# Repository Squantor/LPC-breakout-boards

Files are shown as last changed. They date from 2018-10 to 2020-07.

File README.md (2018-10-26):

# LPC microcontroller breakout boards
This is a small collection breakout boards for various LPC microcontrollers, in the future I might add others to the mix. Currently there are a set of eagle and kicad designs, the eagle designs are legacy and might get replaced in the future as currently I am fully comitting on using kicad.
## checkout notes
This repository contains a few submodules, so after checking out do not forget to also check out the submodules.
```
git clone https://github.com/Squantor/LPC-breakout-boards.git
git submodule init
git submodule update
```
Submodules are my private kicad library that are used in my projects. I do try to use the kicad components as much as possible but for certain component types they are less then optimal.

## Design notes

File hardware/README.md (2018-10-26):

# KiCad LPC breakout boards
We have here a bunch of LPC series microcontroller breakouts. Each of the kicad project dirs contains its own README.
All of the breakouts are using the [squantorPcbLibrary](https://github.com/Squantor/squantorPcbLibrary.git) where needed. Gerbers, and other plots are located per project but only when they have been sent off to production.

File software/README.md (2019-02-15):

# LPC breakout software
Here are some programs to help testing newly built breakout boards, the following tests are executed:
* Programming of the microcontroller
* GPIO's tested for shorts to VDD/VSS and excessive leakage
* Crystal oscillator

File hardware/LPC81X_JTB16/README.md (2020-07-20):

# LPC812 XSON16 breakout
Breakout board for the LPC812 in XSON16 package. This is more or less a test bed to do everything as small as possible. So 0201 components, tiny crystal, everything tiny!
## TODO's
Still some things need to be done:
* schematic entry 
* PCB layout
* Review with one night in between
* Produce at [OSHPARK](https://oshpark.com/)
* Assemble
* Test & characterise
* update Readme.md with pictures and BOM
## BOM
* LPC812M101JTB16
* All passives are 0201

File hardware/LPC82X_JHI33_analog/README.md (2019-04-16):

# LPC824 QFN33 breakout 4 layer version, Analog evaluator
This is a LPC824 breakout for the QFN33 package, all GPIO's are brought out and contains SWD programming header, crystal footprint and a decoupling network (capacitors and ferrite beads) for the analog supplies.

This breakout can be used in prototyping PCB as the breakout headers match the 2.54mm pitch of such a PCB.

This board has a 4 layer stackup to provide a low impedance power supply. The power is also distributed into a digital and analog plane to measure differences in performance of the ADC.
## TODO's
Still some things need to be done:
* layout (Done)
* Review after a day (Done)
* Produce [OSHpark](https://oshpark.com/shared_projects/RuvO87MR) (Done)
* Assemble (Done)
* Full test program (Done)
* Upload some pictures and expand description (Done)
## BOM
Due to the general shortage of passive components, where mentioned, just whatever you can find.
* 0402 100nF 6.3V (generic)
* 0402 Ferrite bead (Murata BLM15PX601SN1D 600Ohm 900mA [Farnell](https://uk.farnell.com/2840091)
* 0402 100Ohm resistors for series dampening of programming lines
* 0402 100KOhm resistors for pullup on Reset, SWDIO and pulldown on SWDCLK
* 0603 1uF 6.3V (generic)
* LPC824 microcontroller [Farnell](https://uk.farnell.com/2890181)
* 12MHz crystal (optional) [Farnell](https://uk.farnell.com/2853917)
* The header I usually get from this vendor on [Ebay](https://www.ebay.com/usr/yixue2010), bit slow shipping and not the cheapest but the parts are good, he has a pretty sizable selection of connectors. 
## Pictures
See the non analog one, physically not a lot of differences.

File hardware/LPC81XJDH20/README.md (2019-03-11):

# LPC81X SSOP20 breakout board
Breakout board of [LPC81X](https://www.nxp.com/products/processors-and-microcontrollers/arm-based-processors-and-mcus/lpc-cortex-m-mcus/lpc800-series-cortex-m0-plus-mcus/low-cost-microcontroll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) microcontroller.
## TODO's
Still some things need to be done:
* Produce at [OSHPARK](https://oshpark.com/shared_projects/42cLyk7C)
* Assemble (TODO)
* Update test program (TODO)
* Update Readme.md with pictures and BOM (TODO)
* Put on sale on tindie

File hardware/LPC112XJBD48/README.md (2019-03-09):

# LPC112X QFP48 breakout board
Breakout board of [LPC112X](https://www.nxp.com/products/processors-and-microcontrollers/arm-based-processors-and-mcus/lpc-cortex-m-mcus/lpc1100-cortex-m0-plus-m0/scalable-entry-level-32-bit-mi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)
## TODO's
Still some things need to be done:
* schematic entry (TODO)
* PCB layout (TODO)
* Review with one night in between (TODO)
* Produce at [OSHPARK](https://oshpark.com/) (TODO)
* Assemble (TODO)
* Test & characterise (TODO)
* update Readme.md with pictures and BOM (TODO)

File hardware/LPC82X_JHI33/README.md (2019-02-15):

# LPC824 QFN33 breakout 2 layer version
This is a LPC824 breakout for the QFN33 package, all GPIO's are brought out and contains SWD programming header, crystal footprint and a decoupling network (capacitors and ferrite beads) for the analog supplies.

This breakout can be used in prototyping PCB as the breakout headers match the 2.54mm pitch of such a PCB.
## TODO's
Still some things need to be done:
* layout (Done)
* Review after a day (Done)
* Produce [OSHpark](https://oshpark.com/shared_projects/RuvO87MR) (Done)
* Assemble (Done)
* Full test program (Done)
* Upload some pictures and expand description (Done)
## BOM
Due to the general shortage of passive components, where mentioned, just whatever you can find.
* 0402 100nF 6.3V (generic)
* 0402 Ferrite bead (Murata BLM15PX601SN1D 600Ohm 900mA [Farnell](https://uk.farnell.com/2840091)
* 0402 100Ohm resistors for series dampening of programming lines
* 0402 100KOhm resistors for pullup on Reset, SWDIO and pulldown on SWDCLK
* 0603 1uF 6.3V (generic)
* LPC824 microcontroller [Farnell](https://uk.farnell.com/2890181)
* 12MHz crystal (optional) [Farnell](https://uk.farnell.com/2853917)
* The header I usually get from this vendor on [Ebay](https://www.ebay.com/usr/yixue2010), bit slow shipping and not the cheapest but the parts are good, he has a pretty sizable selection of connectors. 
## Pictures
This is one of the first PCB's that I assembled with a stencil, leadfree solder and then using a [ZB2020JR temperature controlled hotplate](https://www.aliexpress.com/item/Factory-new-listing-constant-heating-platform-for-smt-assembly-line-model-ZB2020JR/32962615046.html) to solder everything.

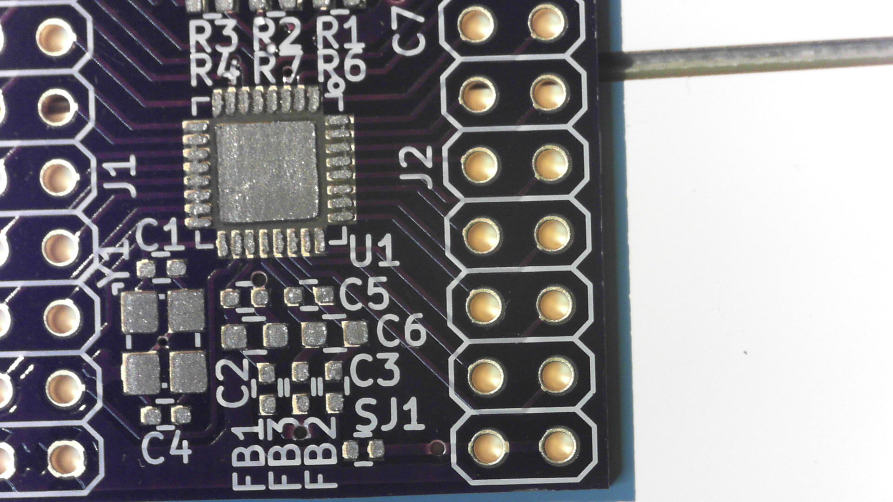
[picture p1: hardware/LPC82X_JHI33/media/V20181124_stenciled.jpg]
V20181124 solder paste stencilled


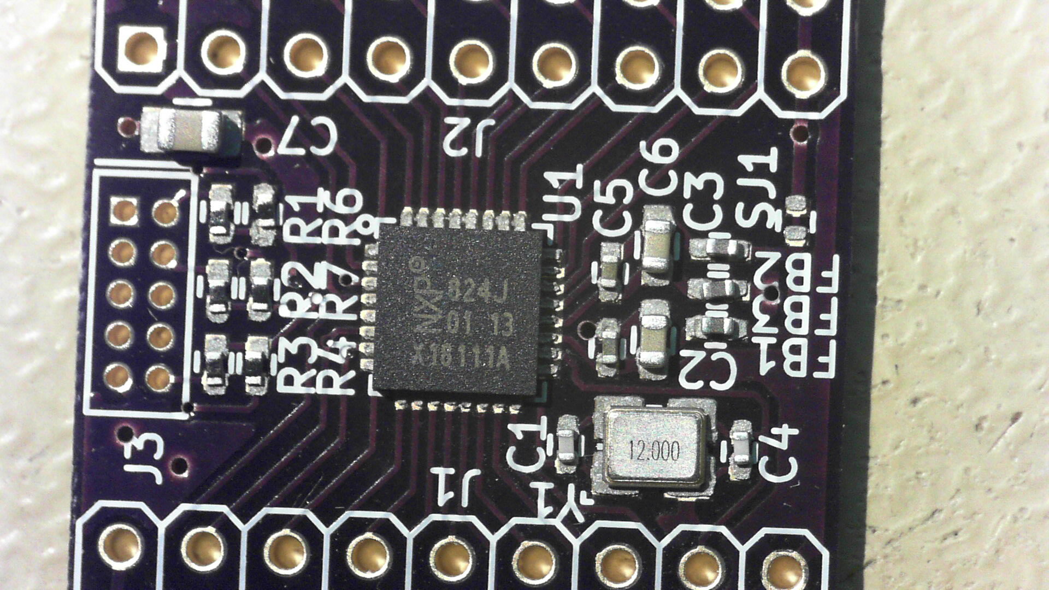
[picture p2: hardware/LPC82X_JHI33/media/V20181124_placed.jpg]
V20181124 components placed


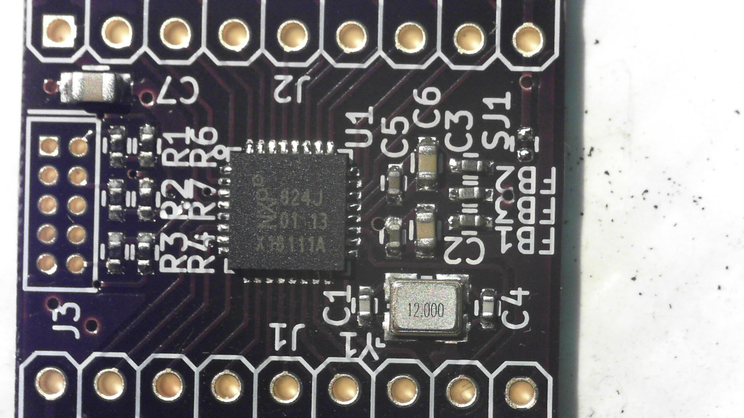
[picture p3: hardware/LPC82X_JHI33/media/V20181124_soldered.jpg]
V20181124 soldered


TODO, pictures of V20181124 on a bed of nails testing jig.

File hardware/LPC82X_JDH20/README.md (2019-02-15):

# LPC824 TSSOP20 breakout
This is a LPC824 breakout for the TSSOP20 package, all GPIO's are brought out and contains SWD programming header, crystal footprint and a decoupling network (capacitors and ferrite beads) for the analog supplies.

This breakout can be used in prototyping PCB and breadboards as the breakout headers have a 2.54mm pitch.
## TODO's
Still some things need to be done:
* schematic entry (Done)
* PCB layout (Done)
* Review with one night in between (Done)
* Produce at [OSHPARK](https://oshpark.com/shared_projects/RIWbBn4d)
* Assemble (Done)
* Full test program (Done)
* Upload some pictures and expand description
## BOM
Due to the general shortage of passive components, where mentioned, just whatever you can find.
* 0402 100nF 6.3V (generic)
* 0402 Ferrite bead (Murata BLM15PX601SN1D 600Ohm 900mA [Farnell](https://uk.farnell.com/2840091)
* 0402 100Ohm resistors for series dampening of programming lines
* 0402 100KOhm resistors for pullup on Reset, SWDIO and pulldown on SWDCLK
* 0603 1uF 6.3V (generic)
* LPC824 microcontroller [Farnell](https://uk.farnell.com/2448376)
* 12MHz crystal (optional) [Farnell](https://uk.farnell.com/2853917)
* The header I usually get from this vendor on [Ebay](https://www.ebay.com/usr/yixue2010), bit slow shipping and not the cheapest but the parts are good, he has a pretty sizable selection of connectors. 
## Photos
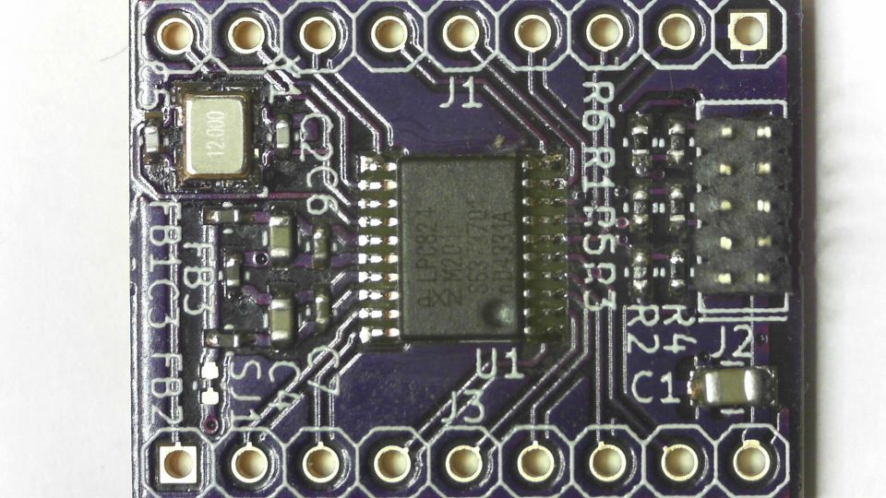
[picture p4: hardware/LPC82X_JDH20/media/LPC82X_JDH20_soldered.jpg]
V20190121 soldered with leaded solder


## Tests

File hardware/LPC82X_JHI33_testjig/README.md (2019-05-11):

# LPC824JHI33 test jig PCB
This PCB is used in the LPC824JHI33 test jig. It contains a network of resistors and capacitors that is used by the test algorithm. See in the software directory the breakout tester how this works in detail.
## TODO's
Still some things need to be done:
* schematic entry (TODO)
* PCB layout (TODO)
* Review with one night in between (TODO)
* Produce at [OSHPARK](https://oshpark.com/) (TODO)
* Assemble (TODO)
* Test & characterise (TODO)
* update Readme.md with pictures and BOM (TODO)

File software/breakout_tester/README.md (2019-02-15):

# LPC824 TSOP20 breakout test program
This software project contains the code to fully test out a LPC824 TSOP20 breakout board.
## checking out
use ```git clone --recurse-submodules https://github.com/Squantor/LPC-breakout-boards.git``` to clone the repo and its submodules.
## compiling
Use make to compile:
```
make debug
```
There is also a release version but not really used. There is also a make target that compiles the proper target (debug or release) and loads it into the board with the selected black magic probe type (ftdi or usb type).
```
make gdbftdidebug
make gdbftdirelease
make gdbusbdebug
make gdbusbrelease
```
If the program hits the end breakpoint at main, the board is okay. Still need to find a nicer way to give visual or audio feedback to the user.
### Depedencies
This program depends on my slightly modified version of [LPCopen](https://github.com/Squantor/lpc_chip_82x.git). This is automatically checked out when using ```git clone --recurse-submodules```.
## usage
To use the software you need the following hardware:
* LPC824 breakout board
* [Black magic probe](https://github.com/blacksphere/blackmagic)
* LPC824 test board, either homebrew or use the bed of nails tester in the hardware subdirectory
## Tests
A set of tests is performed to verify functionality.
### Crystal
The test program first initializes the crystal oscillator, if any problems occur there the program will hang on a while loop while waiting for the crystal oscillator to start oscillating.
### GPIO's
The test algorithm for each GPIO is as follows:
1. Set the adjecent GPIO's to output and to low
2. Set the GPIO to test to input and turn on pull up
3. read GPIO continually with 10ms intervals, due to the capacitor to ground the voltage will slowly climb
4. When a solid high is measured (32 samples) proceed to next step
5. shut off pull up and turn on pull down
6. read GPIO continually with 10ms intervals, due to the capacitor to ground the voltage will slowly fall
7. When a solid low is measured (32 samples) proceed to next step
8. Go to next GPIO in the list
# TODO
The following tasks are still open:
* Importing all the libraries
* make crystal test routine
* make GPIO test routine
* merge all breakout test programs into one unified project
* Start creating the bed of nails tester (hardware task)

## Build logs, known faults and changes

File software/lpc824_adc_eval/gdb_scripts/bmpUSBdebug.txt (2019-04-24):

file bin/debug/lpc824_tryouts.elf
target extended-remote /dev/ttyBmpGdb0
monitor swdp_scan
attach 1
set mem inaccessible-by-default off
set {int}0x40048000 = 2
load bin/debug/lpc824_tryouts.elf
set {int}0x40048000 = 2
compare-sections
b main

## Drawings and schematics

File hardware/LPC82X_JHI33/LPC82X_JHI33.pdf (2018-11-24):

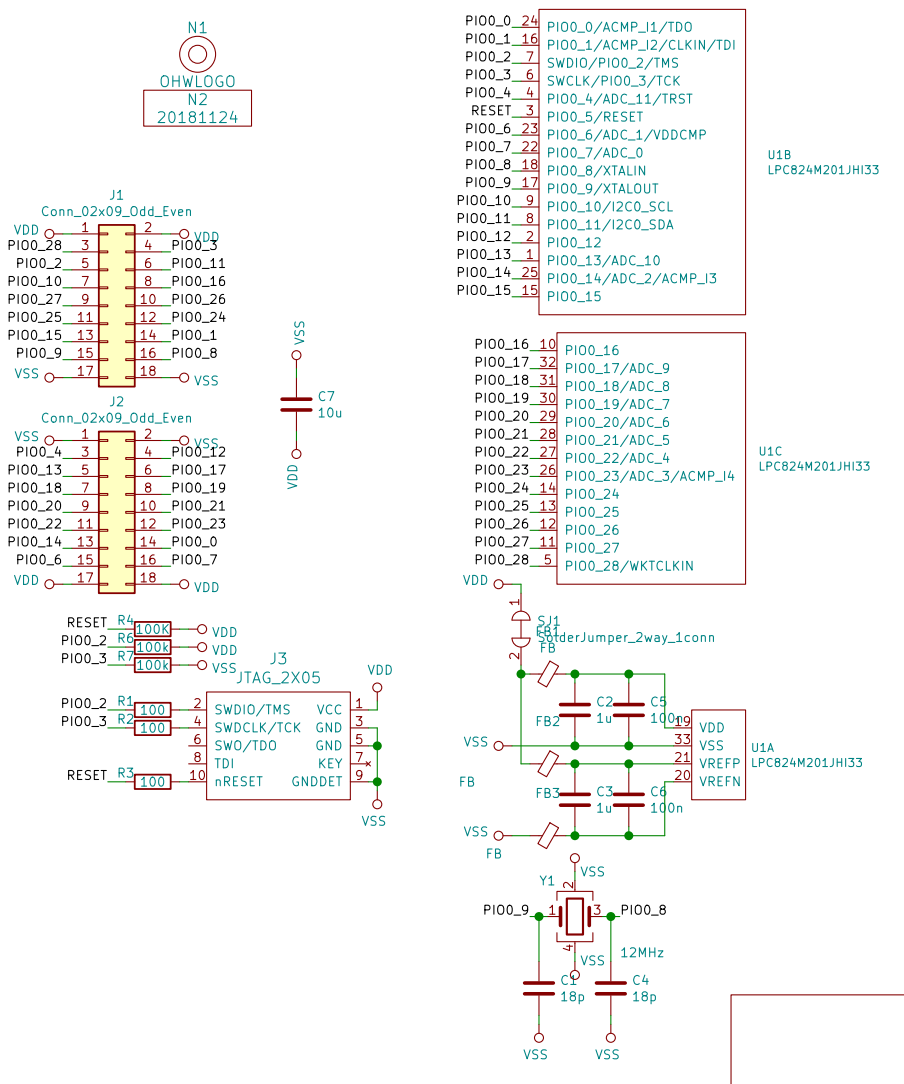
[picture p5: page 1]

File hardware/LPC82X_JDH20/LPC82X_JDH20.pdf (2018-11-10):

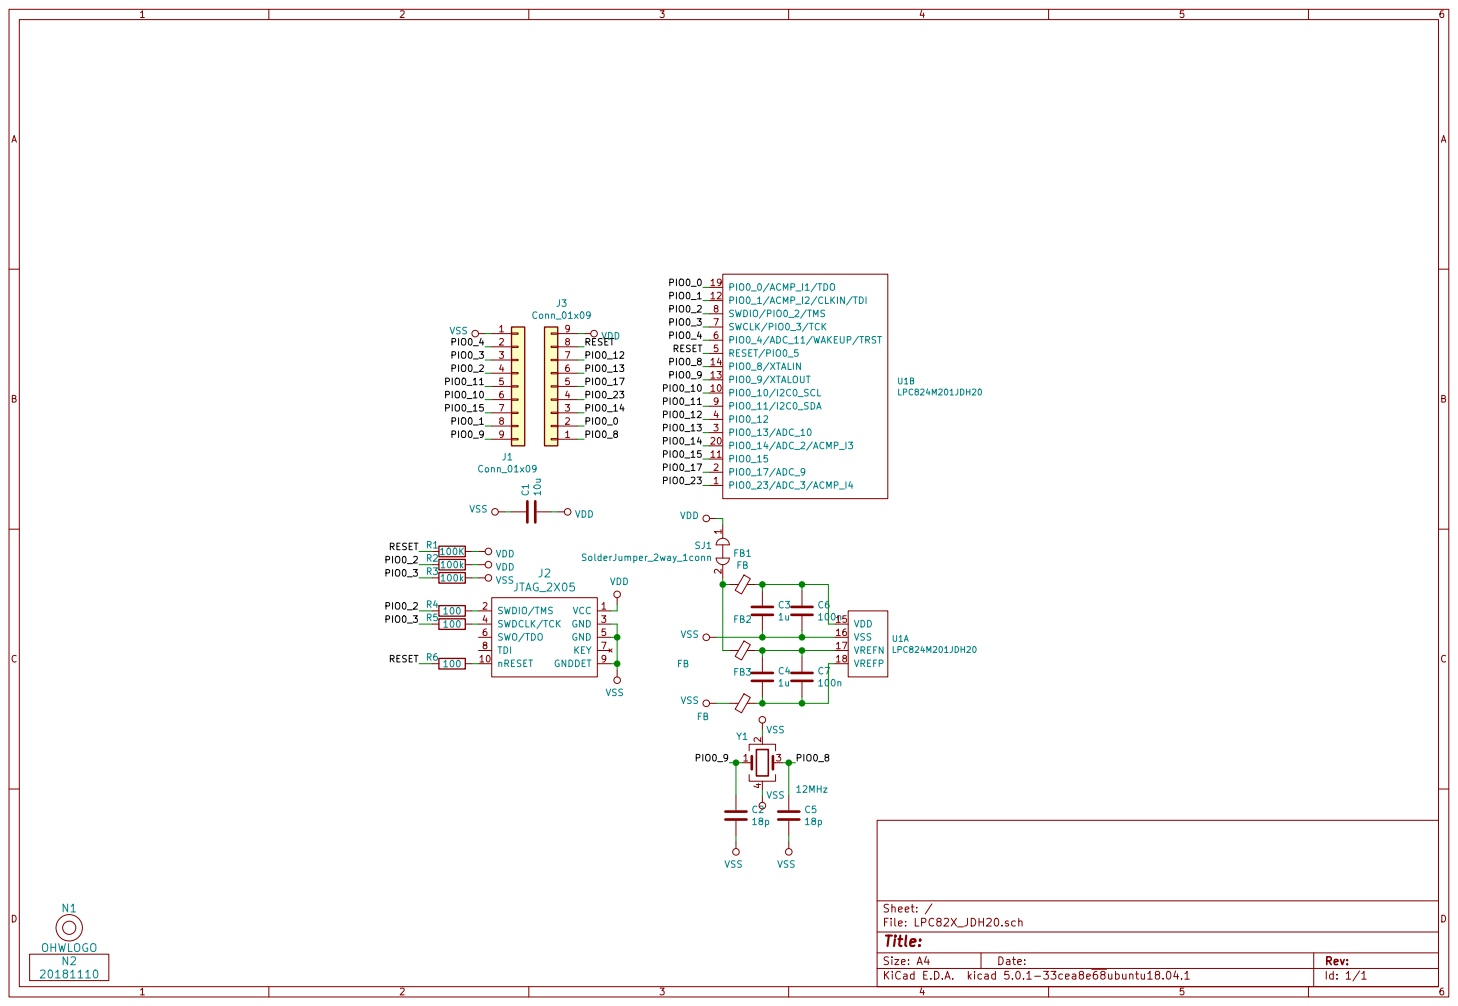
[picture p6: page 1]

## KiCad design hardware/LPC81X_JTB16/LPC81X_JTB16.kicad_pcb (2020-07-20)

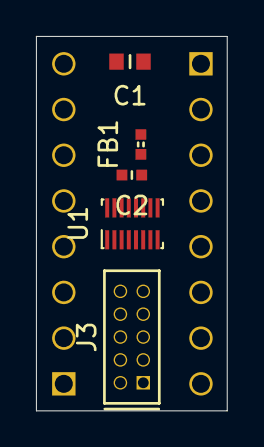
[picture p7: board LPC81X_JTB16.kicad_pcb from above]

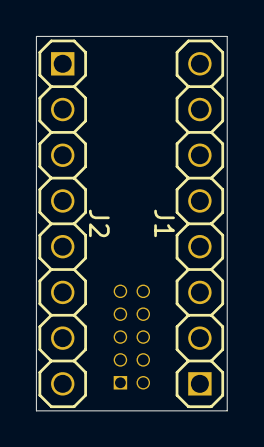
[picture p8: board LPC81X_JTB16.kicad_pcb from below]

Board: 2 copper layers, 10.6 x 20.8 mm, 9 parts (2 on the bottom side), 11 nets, no tracks yet.

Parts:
C1: 10u; C_0603
C2: 1u; C_0402
FB1: 600; L_0402
J1, J2: Conn_01x08; Header-0254-1X08-H010
J3: JTAG_2X05_IN; Header-0127-2X05-H006
N1: 20200720; Label_Generic
N2: OHWLOGO; OSHW-Symbol_6.7x6mm_SilkScreen
U1: LPC812M101JTB16; NXP_XSON-16

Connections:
/PIO0_2: J2.7, U1.6
/PIO0_3: J2.8, U1.5
/PIO0_4: J1.1, U1.4
/PIO0_5: J1.2, U1.3
/PIO0_10: J2.5, U1.8
/PIO0_11: J2.6, U1.7
/PIO0_12: J1.3, U1.2
/PIO0_13: J1.4, U1.1
/VDD: C1.1, FB1.2, J3.1
/VSS: C1.2, C2.2, J3.3, J3.5, J3.9, U1.13
unnamed: C2.1, FB1.1, U1.12

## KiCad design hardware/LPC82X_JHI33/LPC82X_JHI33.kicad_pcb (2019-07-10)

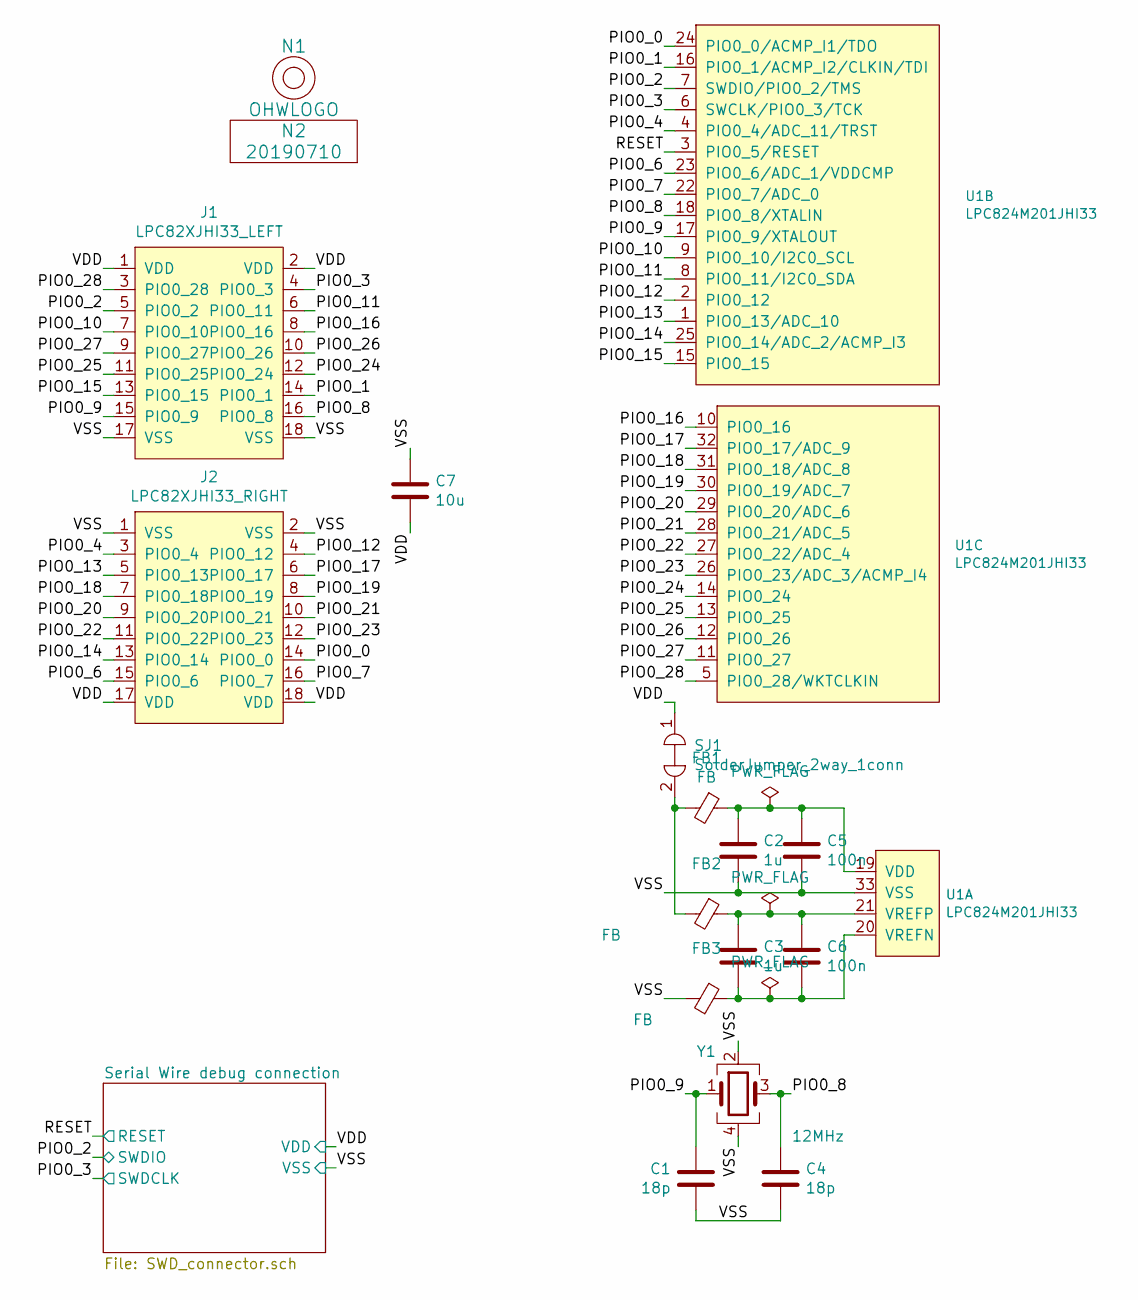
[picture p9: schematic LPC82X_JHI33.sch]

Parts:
C1, C4: 18p; C_0402
C2, C3: 1u; C_0603
C5, C6: 100n; C_0402
C7: 10u; C_0805
FB1, FB2, FB3: FB; C_0402
J1: LPC82XJHI33_LEFT; LPC82XJHI33_breakout_left
J2: LPC82XJHI33_RIGHT; LPC82XJHI33_breakout_right
N1: OHWLOGO; OSHW-Symbol_6.7x6mm_SilkScreen
N2: 20190710; Label_version
SJ1: SolderJumper_2way_1conn; solder_jumper_2way_conn
U1: LPC824M201JHI33; SOT617-3_alt_paste
Y1: 12MHz; Crystal_3225_4

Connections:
/PIO0_0: J2.14 (PIO0_0), U1.24 (PIO0_0/ACMP_I1/TDO)
/PIO0_1: J1.14 (PIO0_1), U1.16 (PIO0_1/ACMP_I2/CLKIN/TDI)
/PIO0_2: J1.5 (PIO0_2), U1.7 (SWDIO/PIO0_2/TMS); also elsewhere on the board
/PIO0_3: J1.4 (PIO0_3), U1.6 (SWCLK/PIO0_3/TCK); also elsewhere on the board
/PIO0_4: J2.3 (PIO0_4), U1.4 (PIO0_4/ADC_11/TRST)
/PIO0_6: J2.15 (PIO0_6), U1.23 (PIO0_6/ADC_1/VDDCMP)
/PIO0_7: J2.16 (PIO0_7), U1.22 (PIO0_7/ADC_0)
/PIO0_8: C4.1, J1.16 (PIO0_8), U1.18 (PIO0_8/XTALIN), Y1.3
/PIO0_9: C1.1, J1.15 (PIO0_9), U1.17 (PIO0_9/XTALOUT), Y1.1
/PIO0_10: J1.7 (PIO0_10), U1.9 (PIO0_10/I2C0_SCL)
/PIO0_11: J1.6 (PIO0_11), U1.8 (PIO0_11/I2C0_SDA)
/PIO0_12: J2.4 (PIO0_12), U1.2 (PIO0_12)
/PIO0_13: J2.5 (PIO0_13), U1.1 (PIO0_13/ADC_10)
/PIO0_14: J2.13 (PIO0_14), U1.25 (PIO0_14/ADC_2/ACMP_I3)
/PIO0_15: J1.13 (PIO0_15), U1.15 (PIO0_15)
/PIO0_16: J1.8 (PIO0_16), U1.10 (PIO0_16)
/PIO0_17: J2.6 (PIO0_17), U1.32 (PIO0_17/ADC_9)
/PIO0_18: J2.7 (PIO0_18), U1.31 (PIO0_18/ADC_8)
/PIO0_19: J2.8 (PIO0_19), U1.30 (PIO0_19/ADC_7)
/PIO0_20: J2.9 (PIO0_20), U1.29 (PIO0_20/ADC_6)
/PIO0_21: J2.10 (PIO0_21), U1.28 (PIO0_21/ADC_5)
/PIO0_22: J2.11 (PIO0_22), U1.27 (PIO0_22/ADC_4)
/PIO0_23: J2.12 (PIO0_23), U1.26 (PIO0_23/ADC_3/ACMP_I4)
/PIO0_24: J1.12 (PIO0_24), U1.14 (PIO0_24)
/PIO0_25: J1.11 (PIO0_25), U1.13 (PIO0_25)
/PIO0_26: J1.10 (PIO0_26), U1.12 (PIO0_26)
/PIO0_27: J1.9 (PIO0_27), U1.11 (PIO0_27)
/PIO0_28: J1.3 (PIO0_28), U1.5 (PIO0_28/WKTCLKIN)
/RESET: U1.3 (PIO0_5/RESET); also elsewhere on the board
/VDD: C7.2, J1.1 (VDD), J1.2 (VDD), J2.17 (VDD), J2.18 (VDD), SJ1.1; also elsewhere on the board
/VSS: C1.2, C2.2, C4.2, C5.2, C7.1, FB3.2, J1.17 (VSS), J1.18 (VSS), J2.1 (VSS), J2.2 (VSS), U1.33 (VSS), Y1.2, Y1.4; also elsewhere on the board
unnamed: C2.1, C5.1, FB1.1, U1.19 (VDD)
unnamed: C3.1, C6.1, FB2.1, U1.21 (VREFP)
unnamed: C3.2, C6.2, FB3.1, U1.20 (VREFN)
unnamed: FB1.2, FB2.2, SJ1.2

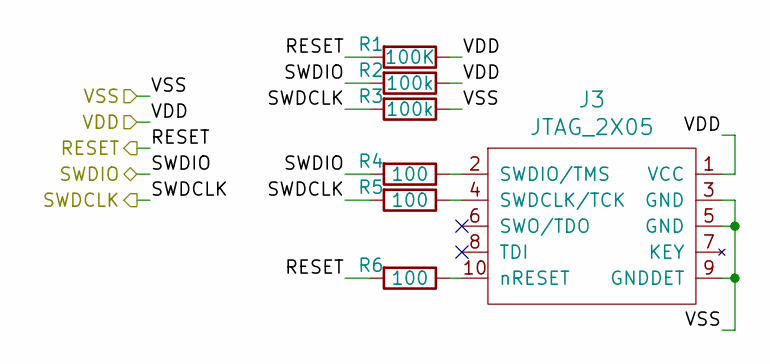
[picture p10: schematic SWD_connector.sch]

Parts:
J3: JTAG_2X05; Header-0127-2X05-H006
R1: 100K; R_0402_hand
R2, R3: 100k; R_0402_hand
R4, R5, R6: 100; R_0402_hand

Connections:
/PIO0_2: R2.2, R4.2; also elsewhere on the board
/PIO0_3: R3.2, R5.2; also elsewhere on the board
/RESET: R1.2, R6.2; also elsewhere on the board
/VDD: J3.1 (VCC), R1.1, R2.1; also elsewhere on the board
/VSS: J3.3 (GND), J3.5 (GND), J3.9 (GNDDET), R3.1; also elsewhere on the board
unnamed: J3.2 (SWDIO/TMS), R4.1
unnamed: J3.4 (SWDCLK/TCK), R5.1
unnamed: J3.10 (nRESET), R6.1

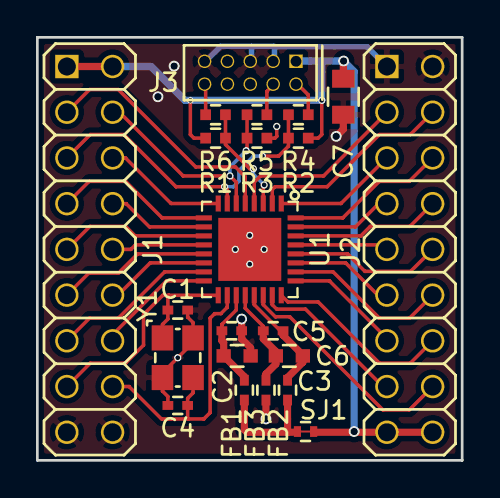
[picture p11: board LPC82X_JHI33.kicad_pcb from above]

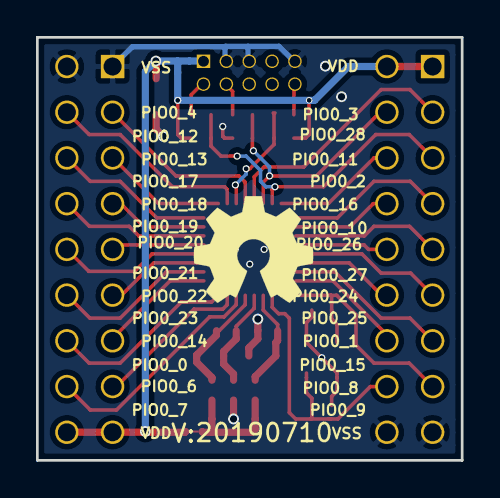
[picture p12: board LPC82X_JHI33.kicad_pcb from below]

Board: 2 copper layers, 23.6 x 23.5 mm, 24 parts (2 on the bottom side), 38 nets.

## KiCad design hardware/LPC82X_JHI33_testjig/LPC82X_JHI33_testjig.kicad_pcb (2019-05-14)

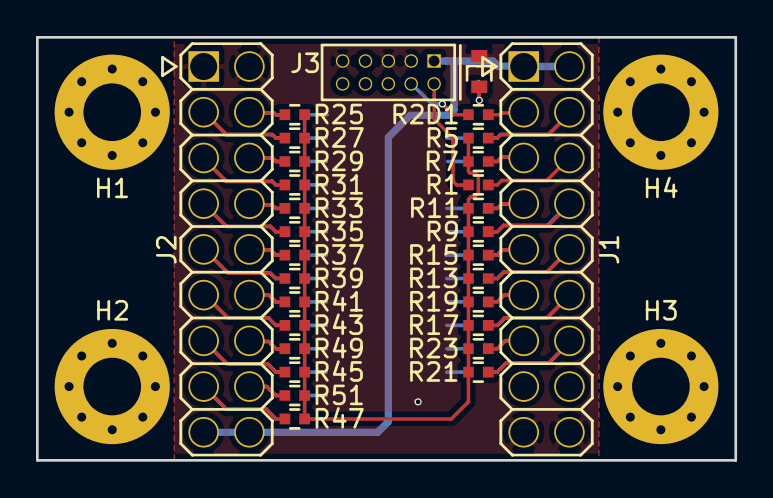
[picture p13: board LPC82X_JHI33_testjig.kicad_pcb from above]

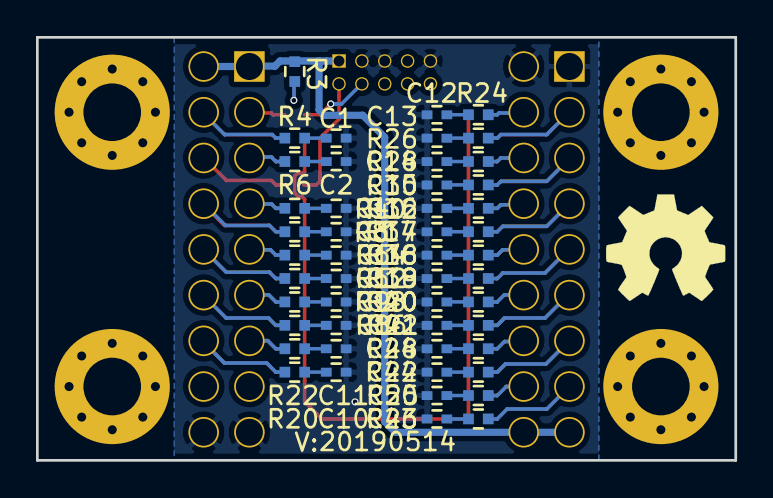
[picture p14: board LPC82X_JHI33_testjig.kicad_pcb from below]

Board: 2 copper layers, 38.8 x 23.5 mm, 85 parts (51 on the bottom side), 56 nets.

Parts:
C1, C2, C3, C4, C5, C6, C8, C9, C10, C11, C12, C13, C14, C15, C16, C17, C18, C19, C20, C21, C22, C23, C24, C25: 1u; C_0402
D1: RED; D_0603_hand
H1, H2, H3, H4: MountingHole; MountingHole_3.2mm_M3_Pad_Via
J1: LPC82XJHI33_LEFT; Header-0254-2X09-H015
J2: LPC82XJHI33_RIGHT; Header-0254-2X09-H015
J3: JTAG_2X05; Header-0127-2X05-H006
N1: OHWLOGO; OSHW-Symbol_6.7x6mm_SilkScreen
N2: 20190514; Label_version
R1, R2: 100; R_0402_hand
R3: 1K; R_0402_hand
R4, R6, R8, R10, R12, R14, R16, R18, R20, R22, R24, R26, R28, R30, R32, R34, R36, R38, R40, R42, R44, R46, R48, R50: 470; R_0402_hand
R5, R7, R9, R11, R13, R15, R17, R19, R21, R23, R25, R27, R29, R31, R33, R35, R37, R39, R41, R43, R45, R47, R49, R51: 100K; R_0402_hand

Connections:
/Digital_stimulus: R5.1, R7.1, R9.1, R11.1, R13.1, R15.1, R17.1, R19.1, R21.1, R23.1, R25.1, R27.1, R29.1, R31.1, R33.1, R35.1, R37.1, R39.1, R41.1, R43.1, R45.1, R47.1, R49.1, R51.1
/PIO0_0: J2.13, R44.2, R45.2
/PIO0_1: J1.13, R22.2, R23.2
/PIO0_2: J1.6, R1.2
/PIO0_3: J1.3, R2.2
/PIO0_4: J2.4, R24.2, R25.2
/PIO0_6: J2.16, R50.2, R51.2
/PIO0_7: J2.15, R46.2, R47.2
/PIO0_10: J1.8, R8.2, R9.2
/PIO0_11: J1.5, R6.2, R7.2
/PIO0_12: J2.3, R26.2, R27.2
/PIO0_13: J2.6, R28.2, R29.2
/PIO0_14: J2.14, R48.2, R49.2
/PIO0_15: J1.14, R20.2, R21.2
/PIO0_16: J1.7, R10.2, R11.2
/PIO0_17: J2.5, R30.2, R31.2
/PIO0_18: J2.8, R32.2, R33.2
/PIO0_19: J2.7, R34.2, R35.2
/PIO0_20: J2.10, R36.2, R37.2
/PIO0_21: J2.9, R38.2, R39.2
/PIO0_22: J2.12, R40.2, R41.2
/PIO0_23: J2.11, R42.2, R43.2
/PIO0_24: J1.11, R18.2, R19.2
/PIO0_25: J1.12, R16.2, R17.2
/PIO0_26: J1.9, R14.2, R15.2
/PIO0_27: J1.10, R12.2, R13.2
/PIO0_28: J1.4, R4.2, R5.2
/VDD: J1.1, J1.2, J2.17, J2.18, J3.1, R3.1
/VSS: C1.2, C2.2, C3.2, C4.2, C5.2, C6.2, C8.2, C9.2, C10.2, C11.2, C12.2, C13.2, C14.2, C15.2, C16.2, C17.2, C18.2, C19.2, C20.2, C21.2, C22.2, C23.2, C24.2, C25.2, D1.1, J1.17, J1.18, J2.1, J2.2, J3.3, J3.5, J3.9
unnamed: C1.1, R4.1
unnamed: C2.1, R6.1
unnamed: C3.1, R8.1
unnamed: C4.1, R10.1
unnamed: C5.1, R12.1
unnamed: C6.1, R14.1
unnamed: C8.1, R16.1
unnamed: C9.1, R18.1
unnamed: C10.1, R20.1
unnamed: C11.1, R22.1
unnamed: C12.1, R24.1
unnamed: C13.1, R26.1
unnamed: C14.1, R28.1
unnamed: C15.1, R30.1
unnamed: C16.1, R32.1
unnamed: C17.1, R34.1
unnamed: C18.1, R36.1
unnamed: C19.1, R38.1
unnamed: C20.1, R40.1
unnamed: C21.1, R42.1
unnamed: C22.1, R44.1
unnamed: C23.1, R46.1
unnamed: C24.1, R48.1
unnamed: C25.1, R50.1
unnamed: D1.2, R3.2
unnamed: J3.2, R1.1
unnamed: J3.4, R2.1

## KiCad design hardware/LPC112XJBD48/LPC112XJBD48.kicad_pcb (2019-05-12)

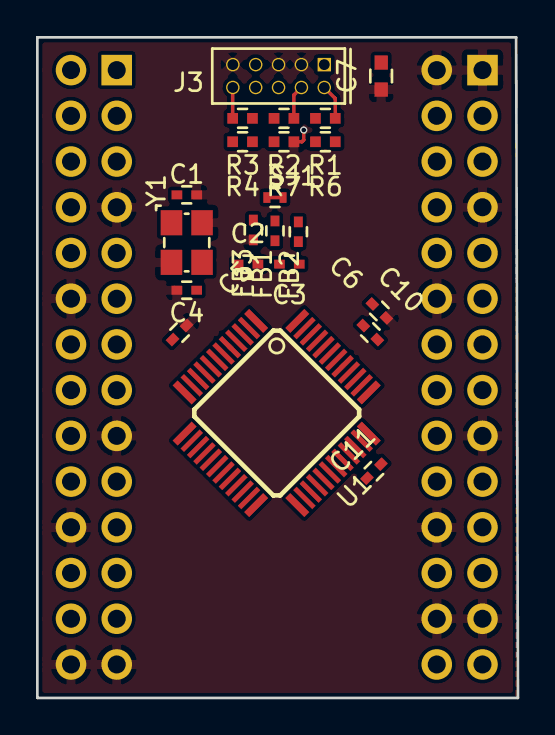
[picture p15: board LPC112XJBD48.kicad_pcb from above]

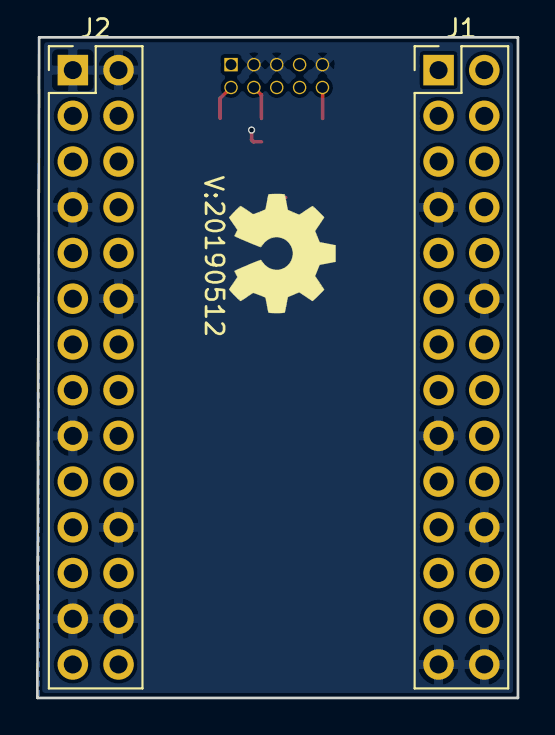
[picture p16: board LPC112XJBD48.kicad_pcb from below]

Board: 2 copper layers, 26.7 x 36.7 mm, 26 parts (4 on the bottom side), 49 nets.

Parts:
C1, C4: 18p; C_0402
C2, C3: 1u; C_0402
C5, C6, C10, C11: 100n; C_0402
C7: 10u; C_0603
FB1, FB2, FB3: 600; C_0402
J1, J2: Conn_02x14_Odd_Even; PinHeader_2x14_P2.54mm_Vertical
J3: JTAG_2X05; Header-0127-2X05-H006
N1: OHWLOGO; OSHW-Symbol_6.7x6mm_SilkScreen
N2: 20190512; Label_version
R1, R2, R3: 100; R_0402_hand
R4: 100K; R_0402_hand
R6, R7: 100k; R_0402_hand
SJ1: SolderJumper_2way_1conn; solder_jumper_2way_conn
U1: LPC1125JBD48_303; SOT313-2-NXP
Y1: 12MHz; Crystal_3225_4

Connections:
/PIO0_1: J1.6, U1.4
/PIO0_2: J1.9, U1.10
/PIO0_3: J1.14, U1.14
/PIO0_4: J1.15, U1.15
/PIO0_5: J1.16, U1.16
/PIO0_6: J1.24, U1.22
/PIO0_7: J1.25, U1.23
/PIO0_8: J2.23, U1.26
/PIO0_9: J2.21, U1.27
/PIO0_10: J2.20, R2.2, R7.2, U1.28
/PIO0_11: J2.18, U1.30
/PIO1_0: J2.16, U1.31
/PIO1_1: J2.15, U1.32
/PIO1_2: J2.14, U1.35
/PIO1_3: J2.10, R1.2, R6.2, U1.38
/PIO1_4: J2.9, U1.39
/PIO1_5: J2.6, U1.45
/PIO1_6: J2.5, U1.46
/PIO1_7: J2.4, U1.47
/PIO1_8: J1.8, U1.9
/PIO1_9: J1.18, U1.17
/PIO1_10: J2.19, U1.29
/PIO1_11: J2.8, U1.42
/PIO2_0: J1.4, U1.2
/PIO2_1: J1.13, U1.13
/PIO2_2: J2.24, U1.25
/PIO2_3: J2.11, U1.37
/PIO2_4: J1.20, U1.19
/PIO2_5: J1.21, U1.20
/PIO2_6: J1.3, U1.1
/PIO2_7: J1.10, U1.11
/PIO2_8: J1.11, U1.12
/PIO2_9: J1.26, U1.24
/PIO3_0: J2.13, U1.36
/PIO3_3: J2.3, U1.48
/PIO3_4: J1.19, U1.18
/PIO3_5: J1.23, U1.21
/RESET: J1.5, R3.2, R4.2, U1.3
/XTALIN: C4.1, U1.6, Y1.3
/XTALOUT: C1.1, U1.7, Y1.1
unnamed: C2.1, C5.1, C10.1, FB1.1, U1.8, U1.44
unnamed: C3.1, C6.1, C11.1, FB2.1, U1.33, U1.43
unnamed: C3.2, C6.2, C11.2, FB3.1, U1.34, U1.40
unnamed: FB1.2, FB2.2, SJ1.1
unnamed: J3.2, R1.1
unnamed: J3.4, R2.1
unnamed: J3.10, R3.1
VDD: C7.2, J1.1, J1.2, J2.27, J2.28, J3.1, R4.1, R6.1, SJ1.2
VSS: C1.2, C2.2, C4.2, C5.2, C7.1, C10.2, FB3.2, J1.7, J1.12, J1.17, J1.22, J1.27, J1.28, J2.1, J2.2, J2.7, J2.12, J2.17, J2.22, J2.25, J2.26, J3.3, J3.5, J3.9, R7.1, U1.5, U1.41, Y1.2, Y1.4

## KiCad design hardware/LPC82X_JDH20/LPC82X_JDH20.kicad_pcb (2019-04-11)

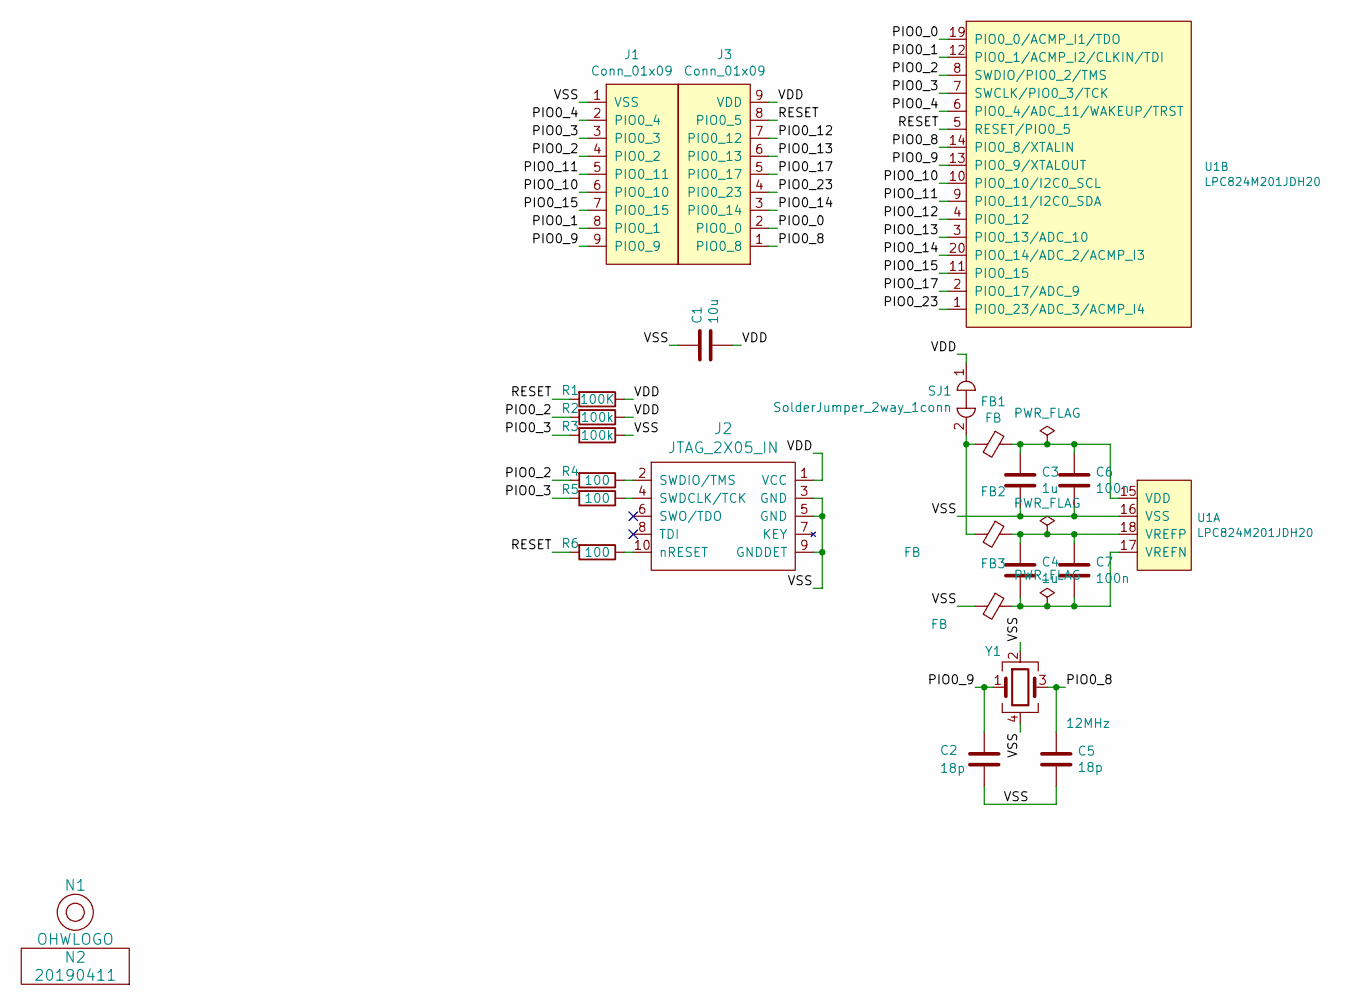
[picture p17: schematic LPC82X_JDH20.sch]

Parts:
C1: 10u; C_0805
C2, C5: 18p; C_0402
C3, C4: 1u; C_0603
C6, C7: 100n; C_0402
FB1, FB2, FB3: FB; C_0402
J1: Conn_01x09; LPC82XJDH20_breakout_left
J2: JTAG_2X05_IN; Header-0127-2X05-H006
J3: Conn_01x09; LPC82XJDH20_breakout_right
N1: OHWLOGO; OSHW-Symbol_6.7x6mm_SilkScreen
N2: 20190411; Label_version
R1: 100K; R_0402_hand
R2, R3: 100k; R_0402_hand
R4, R5, R6: 100; R_0402_hand
SJ1: SolderJumper_2way_1conn; solder_jumper_2way_conn
U1: LPC824M201JDH20; SOT360
Y1: 12MHz; Crystal_3225_4

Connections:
/PIO0_0: J3.2 (PIO0_0), U1.19 (PIO0_0/ACMP_I1/TDO)
/PIO0_1: J1.8 (PIO0_1), U1.12 (PIO0_1/ACMP_I2/CLKIN/TDI)
/PIO0_2: J1.4 (PIO0_2), R2.2, R4.2, U1.8 (SWDIO/PIO0_2/TMS)
/PIO0_3: J1.3 (PIO0_3), R3.2, R5.2, U1.7 (SWCLK/PIO0_3/TCK)
/PIO0_4: J1.2 (PIO0_4), U1.6 (PIO0_4/ADC_11/WAKEUP/TRST)
/PIO0_8: C5.1, J3.1 (PIO0_8), U1.14 (PIO0_8/XTALIN), Y1.3
/PIO0_9: C2.1, J1.9 (PIO0_9), U1.13 (PIO0_9/XTALOUT), Y1.1
/PIO0_10: J1.6 (PIO0_10), U1.10 (PIO0_10/I2C0_SCL)
/PIO0_11: J1.5 (PIO0_11), U1.9 (PIO0_11/I2C0_SDA)
/PIO0_12: J3.7 (PIO0_12), U1.4 (PIO0_12)
/PIO0_13: J3.6 (PIO0_13), U1.3 (PIO0_13/ADC_10)
/PIO0_14: J3.3 (PIO0_14), U1.20 (PIO0_14/ADC_2/ACMP_I3)
/PIO0_15: J1.7 (PIO0_15), U1.11 (PIO0_15)
/PIO0_17: J3.5 (PIO0_17), U1.2 (PIO0_17/ADC_9)
/PIO0_23: J3.4 (PIO0_23), U1.1 (PIO0_23/ADC_3/ACMP_I4)
/RESET: J3.8 (PIO0_5), R1.2, R6.2, U1.5 (RESET/PIO0_5)
/VDD: C1.2, J2.1 (VCC), J3.9 (VDD), R1.1, R2.1, SJ1.1
/VSS: C1.1, C2.2, C3.2, C5.2, C6.2, FB3.2, J1.1 (VSS), J2.3 (GND), J2.5 (GND), J2.9 (GNDDET), R3.1, U1.16 (VSS), Y1.2, Y1.4
unnamed: C3.1, C6.1, FB1.1, U1.15 (VDD)
unnamed: C4.1, C7.1, FB2.1, U1.18 (VREFP)
unnamed: C4.2, C7.2, FB3.1, U1.17 (VREFN)
unnamed: FB1.2, FB2.2, SJ1.2
unnamed: J2.2 (SWDIO/TMS), R4.1
unnamed: J2.4 (SWDCLK/TCK), R5.1
unnamed: J2.10 (nRESET), R6.1

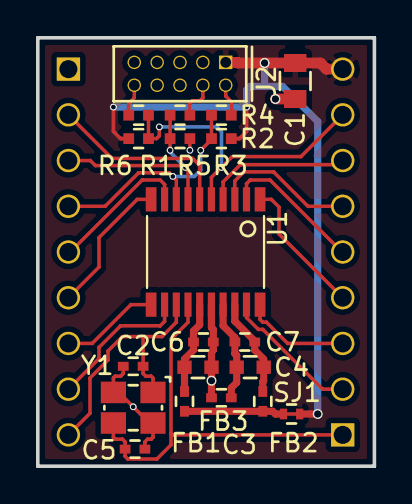
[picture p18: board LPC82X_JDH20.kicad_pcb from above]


Board: 2 copper layers, 18.7 x 23.8 mm, 24 parts (4 on the bottom side), 25 nets.

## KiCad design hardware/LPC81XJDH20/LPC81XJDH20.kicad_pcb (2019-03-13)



Board: 2 copper layers, 18.4 x 26.0 mm, 20 parts (4 on the bottom side), 25 nets.

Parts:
C1: 10u; C_0805
C2, C5: 18p; C_0402
C3: 1u; C_0603
C6: 100n; C_0402
FB1: FB; C_0402
J1: LPC81XJDH20_breakout_left
J2: JTAG_2X05; Header-0127-2X05-H006
J3: LPC81XJDH20_breakout_right
N1: OHWLOGO; OSHW-Symbol_6.7x6mm_SilkScreen
N2: 20190313; Label_version
R1: 100K; R_0402_hand
R2, R3: 100k; R_0402_hand
R4, R5, R6: 33; R_0402_hand
SJ1: SolderJumper_2way_1conn; solder_jumper_2way_conn
U3: LPC812M101JDH20; SOT360
Y1: 12MHz; Crystal_3225_4

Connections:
/PIO0_0: J3.3, U3.19
/PIO0_1: J1.8, U3.12
/PIO0_2: J1.3, R2.2, R4.2, U3.7
/PIO0_3: J1.2, R3.2, R5.2, U3.6
/PIO0_4: J3.9, U3.5
/PIO0_6: J3.2, U3.18
/PIO0_7: J3.1, U3.17
/PIO0_8: C5.1, J1.10, U3.14, Y1.3
/PIO0_9: C2.1, J1.9, U3.13, Y1.1
/PIO0_10: J1.5, U3.9
/PIO0_11: J1.4, U3.8
/PIO0_12: J3.7, U3.3
/PIO0_13: J3.6, U3.2
/PIO0_14: J3.4, U3.20
/PIO0_15: J1.7, U3.11
/PIO0_16: J1.6, U3.10
/PIO0_17: J3.5, U3.1
/RESET: J3.8, R1.2, R6.2, U3.4
unnamed: C3.1, C6.1, FB1.1, U3.15
unnamed: FB1.2, SJ1.2
unnamed: J2.2, R4.1
unnamed: J2.4, R5.1
unnamed: J2.10, R6.1
VDD: C1.2, J2.1, J3.10, R1.1, R2.1, SJ1.1
VSS: C1.1, C2.2, C3.2, C5.2, C6.2, J1.1, J2.3, J2.5, J2.9, R3.1, U3.16, Y1.2, Y1.4

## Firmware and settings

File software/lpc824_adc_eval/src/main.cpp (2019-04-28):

/*
The MIT License (MIT)

Copyright (c) 2018 Bart Bilos

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
THE SOFTWARE IS PROVIDED "AS IS", WITHOUT WARRANTY OF ANY KIND, EXPRESS OR
IMPLIED, INCLUDING BUT NOT LIMITED TO THE WARRANTIES OF MERCHANTABILITY,
FITNESS FOR A PARTICULAR PURPOSE AND NONINFRINGEMENT. IN NO EVENT SHALL THE
AUTHORS OR COPYRIGHT HOLDERS BE LIABLE FOR ANY CLAIM, DAMAGES OR OTHER
LIABILITY, WHETHER IN AN ACTION OF CONTRACT, TORT OR OTHERWISE, ARISING FROM,
OUT OF OR IN CONNECTION WITH THE SOFTWARE OR THE USE OR OTHER DEALINGS IN THE
SOFTWARE.
*/
/*
Main program entry/file.
*/

#include "chip.h"
#include <cr_section_macros.h>
#include <board.hpp>
#include <stream_uart.hpp>
#include <strings.hpp>
#include <print.h>
#include <prompt_mini.h>
#include <command_mini.h>
#include <commands.hpp>

char promptBuf[5];
result cmdlineParse(char *cmdline);

promptData_t adcEvalPromptData = 
{
    promptBuf,
    0,
    sizeof(promptBuf),
    cmdlineParse,
};

volatile uint32_t ticks = 0;
volatile bool sequenceComplete, thresholdCrossed;

extern "C"
{
    void SysTick_Handler(void)
    {
        ticks++;
        /* Manual start for ADC conversion sequence A */
        Chip_ADC_StartSequencer(LPC_ADC, ADC_SEQA_IDX);
    }

    void ADC_SEQA_IRQHandler(void)
    {
        uint32_t pending;

        /* Get pending interrupts */
        pending = Chip_ADC_GetFlags(LPC_ADC);

        /* Sequence A completion interrupt */
        if (pending & ADC_FLAGS_SEQA_INT_MASK) {
            sequenceComplete = true;
        }

        /* Clear any pending interrupts */
        Chip_ADC_ClearFlags(LPC_ADC, pending);
    }
}

result cmdlineParse(char *const cmdline)
{
    return commandInterpret(adcEvalCommands, cmdline);
}

int main(void)
{
    boardInit(); 

    SysTick_Config(SystemCoreClock / TICKRATE_HZ);
    
    dsPuts(&streamUart, strHello);

    while (1)
    {
        promptProcess(&adcEvalPromptData, &streamUart);
        
        /* Is a conversion sequence complete? */
        if(sequenceComplete) 
        {
            sequenceComplete = false;

            /* Get raw sample data for channels 0-11 */
            for (uint16_t i = 0; i < 12; i++) {
                uint32_t rawSample = Chip_ADC_GetDataReg(LPC_ADC, i);

                /* Show some ADC data */
                if (rawSample & (ADC_DR_OVERRUN | ADC_SEQ_GDAT_DATAVALID)) 
                {
                    printDecNzU16(&streamUart, i);
                    dsPuts(&streamUart, strIs);
                    printDecU16(&streamUart, ADC_DR_RESULT(rawSample));
                    dsPuts(&streamUart, strSep);
                }
            }
            dsPuts(&streamUart, strCrLf);
        }
    }

    return 0 ;
}

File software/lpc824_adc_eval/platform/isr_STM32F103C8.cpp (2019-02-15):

/*
MIT License

Copyright (c) 2019 Bart Bilos

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
THE SOFTWARE IS PROVIDED "AS IS", WITHOUT WARRANTY OF ANY KIND, EXPRESS OR
IMPLIED, INCLUDING BUT NOT LIMITED TO THE WARRANTIES OF MERCHANTABILITY,
FITNESS FOR A PARTICULAR PURPOSE AND NONINFRINGEMENT. IN NO EVENT SHALL THE
AUTHORS OR COPYRIGHT HOLDERS BE LIABLE FOR ANY CLAIM, DAMAGES OR OTHER
LIABILITY, WHETHER IN AN ACTION OF CONTRACT, TORT OR OTHERWISE, ARISING FROM,
OUT OF OR IN CONNECTION WITH THE SOFTWARE OR THE USE OR OTHER DEALINGS IN THE
SOFTWARE.
*/

#if defined (__cplusplus)
extern "C" {
#endif

void WWDG_IRQHandler(void) __attribute__((weak, alias("Dummy_Handler")));
void PVD_IRQHandler(void) __attribute__((weak, alias("Dummy_Handler")));
void TAMPER_IRQHandler(void) __attribute__((weak, alias("Dummy_Handler")));
void RTC_IRQHandler(void) __attribute__((weak, alias("Dummy_Handler")));
void FLASH_IRQHandler(void) __attribute__((weak, alias("Dummy_Handler")));
void RCC_IRQHandler(void) __attribute__((weak, alias("Dummy_Handler")));
void EXTI0_IRQHandler(void) __attribute__((weak, alias("Dummy_Handler")));
void EXTI1_IRQHandler(void) __attribute__((weak, alias("Dummy_Handler")));
void EXTI2_IRQHandler(void) __attribute__((weak, alias("Dummy_Handler")));
void EXTI3_IRQHandler(void) __attribute__((weak, alias("Dummy_Handler")));
void EXTI4_IRQHandler(void) __attribute__((weak, alias("Dummy_Handler")));
void DMA1_Channel1_IRQHandler(void) __attribute__((weak, alias("Dummy_Handler")));
void DMA1_Channel2_IRQHandler(void) __attribute__((weak, alias("Dummy_Handler")));
void DMA1_Channel3_IRQHandler(void) __attribute__((weak, alias("Dummy_Handler")));
void DMA1_Channel4_IRQHandler(void) __attribute__((weak, alias("Dummy_Handler")));
void DMA1_Channel5_IRQHandler(void) __attribute__((weak, alias("Dummy_Handler")));
void DMA1_Channel6_IRQHandler(void) __attribute__((weak, alias("Dummy_Handler")));
void DMA1_Channel7_IRQHandler(void) __attribute__((weak, alias("Dummy_Handler")));
void ADC1_2_IRQHandler(void) __attribute__((weak, alias("Dummy_Handler")));
void USB_HP_CAN_TX_IRQHandler(void) __attribute__((weak, alias("Dummy_Handler")));
void USB_LP_CAN_RX0_IRQHandler(void) __attribute__((weak, alias("Dummy_Handler")));
void CAN_RX1_IRQHandler(void) __attribute__((weak, alias("Dummy_Handler")));
void CAN_SCE_IRQHandler(void) __attribute__((weak, alias("Dummy_Handler")));
void EXTI9_5_IRQHandler(void) __attribute__((weak, alias("Dummy_Handler")));
void TIM1_BRK_IRQHandler(void) __attribute__((weak, alias("Dummy_Handler")));
void TIM1_UP_IRQHandler(void) __attribute__((weak, alias("Dummy_Handler")));
void TIM1_TRG_COM_IRQHandler(void) __attribute__((weak, alias("Dummy_Handler")));
void TIM1_CC_IRQHandler(void) __attribute__((weak, alias("Dummy_Handler")));
void TIM2_IRQHandler(void) __attribute__((weak, alias("Dummy_Handler")));
void TIM3_IRQHandler(void) __attribute__((weak, alias("Dummy_Handler")));
void TIM4_IRQHandler(void) __attribute__((weak, alias("Dummy_Handler")));
void I2C1_EV_IRQHandler(void) __attribute__((weak, alias("Dummy_Handler")));
void I2C1_ER_IRQHandler(void) __attribute__((weak, alias("Dummy_Handler")));
void I2C2_EV_IRQHandler(void) __attribute__((weak, alias("Dummy_Handler")));
void I2C2_ER_IRQHandler(void) __attribute__((weak, alias("Dummy_Handler")));
void SPI1_IRQHandler(void) __attribute__((weak, alias("Dummy_Handler")));
void SPI2_IRQHandler(void) __attribute__((weak, alias("Dummy_Handler")));
void USART1_IRQHandler(void) __attribute__((weak, alias("Dummy_Handler")));
void USART2_IRQHandler(void) __attribute__((weak, alias("Dummy_Handler")));
void USART3_IRQHandler(void) __attribute__((weak, alias("Dummy_Handler")));
void EXTI15_10_IRQHandler(void) __attribute__((weak, alias("Dummy_Handler")));
void RTCAlarm_IRQHandler(void) __attribute__((weak, alias("Dummy_Handler")));
void USBWakeup_IRQHandler(void) __attribute__((weak, alias("Dummy_Handler")));
void TIM8_BRK_IRQHandler(void) __attribute__((weak, alias("Dummy_Handler")));
void TIM8_UP_IRQHandler(void) __attribute__((weak, alias("Dummy_Handler")));
void TIM8_TRG_COM_IRQHandler(void) __attribute__((weak, alias("Dummy_Handler")));
void TIM8_CC_IRQHandler(void) __attribute__((weak, alias("Dummy_Handler")));
void ADC3_IRQHandler(void) __attribute__((weak, alias("Dummy_Handler")));
void FSMC_IRQHandler(void) __attribute__((weak, alias("Dummy_Handler")));
void SDIO_IRQHandler(void) __attribute__((weak, alias("Dummy_Handler")));
void TIM5_IRQHandler(void) __attribute__((weak, alias("Dummy_Handler")));
void SPI3_IRQHandler(void) __attribute__((weak, alias("Dummy_Handler")));
void UART4_IRQHandler(void) __attribute__((weak, alias("Dummy_Handler")));
void UART5_IRQHandler(void) __attribute__((weak, alias("Dummy_Handler")));
void TIM6_IRQHandler(void) __attribute__((weak, alias("Dummy_Handler")));
void TIM7_IRQHandler(void) __attribute__((weak, alias("Dummy_Handler")));
void DMA2_Channel1_IRQHandler(void) __attribute__((weak, alias("Dummy_Handler")));
void DMA2_Channel2_IRQHandler(void) __attribute__((weak, alias("Dummy_Handler")));
void DMA2_Channel3_IRQHandler(void) __attribute__((weak, alias("Dummy_Handler")));
void DMA2_Channel4_5_IRQHandler(void) __attribute__((weak, alias("Dummy_Handler")));

#if defined (__cplusplus)
} // extern "C"
#endif

extern void (* const vendor_vector_table[])(void);
void (* const vendor_vector_table[])(void) __attribute__ ((used,section(".vendor_vectors"))) = {
    WWDG_IRQHandler,
    PVD_IRQHandler,
    TAMPER_IRQHandler,
    RTC_IRQHandler,
    FLASH_IRQHandler,
    RCC_IRQHandler,
    EXTI0_IRQHandler,
    EXTI1_IRQHandler,
    EXTI2_IRQHandler,
    EXTI3_IRQHandler,
    EXTI4_IRQHandler,
    DMA1_Channel1_IRQHandler,
    DMA1_Channel2_IRQHandler,
    DMA1_Channel3_IRQHandler,
    DMA1_Channel4_IRQHandler,
    DMA1_Channel5_IRQHandler,
    DMA1_Channel6_IRQHandler,
    DMA1_Channel7_IRQHandler,
    ADC1_2_IRQHandler,
    USB_HP_CAN_TX_IRQHandler,
    USB_LP_CAN_RX0_IRQHandler,
    CAN_RX1_IRQHandler,
    CAN_SCE_IRQHandler,
    EXTI9_5_IRQHandler,
    TIM1_BRK_IRQHandler,
    TIM1_UP_IRQHandler,
    TIM1_TRG_COM_IRQHandler,
    TIM1_CC_IRQHandler,
    TIM2_IRQHandler,
    TIM3_IRQHandler,
    TIM4_IRQHandler,
    I2C1_EV_IRQHandler,
    I2C1_ER_IRQHandler,
    I2C2_EV_IRQHandler,
    I2C2_ER_IRQHandler,
    SPI1_IRQHandler,
    SPI2_IRQHandler,
    USART1_IRQHandler,
    USART2_IRQHandler,
    USART3_IRQHandler,
    EXTI15_10_IRQHandler,
    RTCAlarm_IRQHandler,
    USBWakeup_IRQHandler,
    TIM8_BRK_IRQHandler,
    TIM8_UP_IRQHandler,
    TIM8_TRG_COM_IRQHandler,
    TIM8_CC_IRQHandler,
    ADC3_IRQHandler,
    FSMC_IRQHandler,
    SDIO_IRQHandler,
    TIM5_IRQHandler,
    SPI3_IRQHandler,
    UART4_IRQHandler,
    UART5_IRQHandler,
    TIM6_IRQHandler,
    TIM7_IRQHandler,
    DMA2_Channel1_IRQHandler,
    DMA2_Channel2_IRQHandler,
    DMA2_Channel3_IRQHandler,
    DMA2_Channel4_5_IRQHandler,
};

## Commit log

2014-04-18 * populating with BRD and SCH files
    [LPC800_TSSOP_breadboard.brd, LPC800_TSSOP_breadboard.sch]
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2014-04-24 * small fixes on TODO list
    [LPC800_TSSOP_breadboard.brd, LPC800_TSSOP_breadboard.sch]
2014-04-25 * doing some TODO's
    [LPC800_TSSOP_breadboard.brd]
2014-04-30 * updated board and schem with todo's
    [LPC800_TSSOP_breadboard.brd, LPC800_TSSOP_breadboard.sch]
2014-05-01 * small beautification mods
    [LPC800_TSSOP_breadboard.brd]
2014-05-11 * minor updates with silk, pinout documentation, hole expansion
    [LPC800_TSSOP_breadboard.brd, LPC800_TSSOP_breadboard.sch]
2014-05-29 * small modifications * improved regulator decoupling capacitor position to leave more space for the pinheaders * improved crystal positioning to leave more space for the pinheaders
    [LPC800_TSSOP_breadboard.brd, LPC800_TSSOP_breadboard.sch]
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2014-09-26 * added low cost lpc812 breadboard breakout (mini)
    [LPC800_TSSOP_breadboard_mini.brd, LPC800_TSSOP_breadboard_mini.sch]
2014-09-28 * finished LPC800 mini board * fixed pin 1 for JTAG connection - TODO: Printout inspection and checks for the button layout
    [LPC800_TSSOP_breadboard.brd, LPC800_TSSOP_breadboard_mini.brd, LPC800_TSSOP_breadboard_mini.sch]
2014-10-08 * updated boards with cheaper buttons, better layout and indexed JTAG header
    [LPC800_TSSOP_breadboard.brd, LPC800_TSSOP_breadboard.sch, LPC800_TSSOP_breadboard_mini.brd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]
2014-10-09 * small changes preparing for commit to OSH park
    [LPC800_TSSOP_breadboard.brd, LPC800_TSSOP_breadboard.sch, LPC800_TSSOP_breadboard_mini.brd]
2014-10-09 * added final bits and pieces * updated readme
    [LPC800_TSSOP_breadboard.brd, LPC800_TSSOP_breadboard_mini.brd]
2015-02-20 * renamed LPC800 references to LPC81X * started with LPC82X boards, still need to add the MLF style packages
    [LPC81X_TSSOP_breadboard.brd, LPC81X_TSSOP_breadboard.sch, LPC81X_TSSOP_breadboard_mini.brd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]
2015-02-26 * started with lpc824 TSSOP breakout
    [LPC82X_TSSOP_breadboard_mini.brd, LPC82X_TSSOP_breadboard_mini.sch]
2015-11-22 * fixed some small mistakes
    [LPC800_TSSOP_breadboard.brd, LPC800_TSSOP_breadboard_mini.brd]
2017-01-07 * big cleanup/move of files
    [LPC81X_TSSOP_breadboard.brd, LPC81X_TSSOP_breadboard.sch, LPC81X_TSSOP_breadboard_mini.brd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]
2017-01-07 * added kicad starts for the LPC824 breakouts
    [LPC824_HVQFN33_breakout.kicad_pcb, LPC824_HVQFN33_breakout.sch, LPC824_TSSOP20_breakout.kicad_pcb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]
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2017-01-09 * small updates to the LPC824 breakouts
    [LPC824_HVQFN33_breakout.kicad_pcb, LPC824_HVQFN33_breakout.sch, LPC824_TSSOP20_breakout.kicad_pcb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]
2017-01-12 * updated LPC824 breakout
    [LPC824_HVQFN33_breakout.kicad_pcb, LPC824_HVQFN33_breakout.sch]
2017-01-12 * small schematic updates
    [LPC824_HVQFN33_breakout.sch]
2017-01-23 * fully connected up connectors - next JTAG connection
    [LPC824_HVQFN33_breakout.kicad_pcb, LPC824_HVQFN33_breakout.sch]
2017-01-23 * further layout of the LPC824 chip
    [LPC824_HVQFN33_breakout.kicad_pcb, LPC824_HVQFN33_breakout.sch]
2017-03-21 * added a few parts to the LPC824 breakout
    [LPC824_TSSOP20_breakout.sch]
2017-03-21 * completed breakout board schematic * started with layout of breakout
    [LPC824_TSSOP20_breakout.kicad_pcb, LPC824_TSSOP20_breakout.sch]
2018-10-26 time to update this project and revisit most of the boards with new insights
    [LPC824_HVQFN33_breakout.kicad_pcb, LPC824_HVQFN33_breakout.sch, LPC824_TSSOP20_breakout.kicad_pcb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]
2018-10-26 regenerated kicad projects with submodule
    [LPC82X_JDH20.kicad_pcb, LPC82X_JDH20.sch, LPC82X_JHI33.kicad_pcb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]
2018-10-26 started on LPC824 QFN33 breakout
    [LPC82X_JHI33.kicad_pcb, LPC82X_JHI33.sch]
2018-10-26 started with schematic entry of QFN33 LPC824 breakout
    [LPC82X_JHI33.sch]
2018-10-26 more schematic updates updated footprint of a used button
    [LPC82X_JHI33.sch]
2018-10-26 updated with solder jumper schematic symbols added some jumpers to the QFN33 breakout
    [LPC82X_JHI33.sch]
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2018-10-28 added LPC824 QFN33 breakout on two layers (quicker production) added readme
    [LPC82X_JHI33_2layer.kicad_pcb, LPC82X_JHI33_2layer.sch]
2018-10-28 differentiating rename from 4 layer to 2 layer
    [LPC82X_JHI33.kicad_pcb, LPC82X_JHI33.sch]
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2018-10-28 added bulk decoupling 0805 increased clearance of ground plane
    [LPC82X_JHI33_2layer.kicad_pcb, LPC82X_JHI33_2layer.sch]
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2018-10-29 removed some parts from schematics to simplify the breakout
    [LPC82X_JHI33_2layer.sch]
2018-10-29 updated schematic bits updated board and rerouted with some deletions, lets see if we can shrink the board a bit
    [LPC82X_JHI33_2layer.kicad_pcb, LPC82X_JHI33_2layer.sch]
2018-10-30 reduced PCB size, rerouting large parts of it
    [LPC82X_JHI33_2layer.kicad_pcb]
2018-10-31 updated schematic, added VDD jumper, added top groundplane, completed layout
    [LPC82X_JHI33_2layer.kicad_pcb, LPC82X_JHI33_2layer.sch]
2018-10-31 updated pcb and fixed some inconsistencies
    [LPC82X_JHI33_2layer.kicad_pcb]
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2018-11-09 updated a few traces and silk screen bits
    [LPC82X_JDH20.kicad_pcb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]
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2018-11-22 fixed incorrect crystal footprint
    [LPC82X_JHI33_2layer.kicad_pcb]
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2018-11-22 updated silk mistakes
    [LPC82X_JHI33_2layer.kicad_pcb]
2018-11-22 updated plots with fixed silk
    [LPC82X_JHI33_2layer-B.Cu.gbl, LPC82X_JHI33_2layer-B.Mask.gbs, LPC82X_JHI33_2layer-B.Paste.gbp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]
2018-11-23 fixed DRC error on PCB, fixed resistor positions, updated versionnumber
    [LPC82X_JHI33_2layer.kicad_pcb]
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2018-11-24 updated versionnumber, fixed unrouted trace
    [LPC82X_JHI33_2layer.kicad_pcb, LPC82X_JHI33_2layer.sch]
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2019-01-18 fixed incorrect crystal footprint and relayout
    [LPC82X_JDH20.kicad_pcb]
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2019-01-20 fixed mistake in microcontroller power, updated library component, added newer component library, rerouted
    [LPC82X_JDH20.kicad_pcb, LPC82X_JDH20.sch]
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2019-02-15 first testing GPIO works, now to fix all the TODO's
    [main.cpp]
2019-02-15 added some delays, need to fix this more nicely
    [main.cpp]
2019-02-15 added additional check so we never get stuck forever waiting
    [main.cpp]
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2019-03-10 updated pcb library, replaced LPC824 with LPC812
    [LPC81XJDH20.sch]
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2019-03-11 fixed mistake with shrunk groundplane, updated readme
    [LPC81XJDH20.kicad_pcb]
2019-03-13 newer LPC812 schematic component, changed paste vs pad
    [LPC81XJDH20.kicad_pcb, LPC81XJDH20.sch]
2019-03-13 LPC824 QFN33 new footprint for LPC and shrunk paste size
    [LPC82X_JHI33.kicad_pcb, LPC82X_JHI33.sch]
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2019-03-31 gpio tests operational, but still too low timings from Lo to Hi, disabled optimization in Debug
    [gpio_tester.cpp]
2019-04-04 fixed bug, reworking pin test algorithm fixed a bug with incorrect MCU selection, pin test algorithm depends too much on gpio characteristics and we dont check both charging slopes
    [gpio_tester.cpp]
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2019-04-10 test routine returns failing GPIO, enabled all pins for LPC812
    [gpio_tester.cpp, main.cpp]
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2019-04-16 updated schematic, partial layout of new planes and reduction of components
    [LPC82X_JHI33_analog.kicad_pcb, LPC82X_JHI33_analog.sch]
2019-04-17 updated to named pcb connectors, further plane addition, inital silk placement
    [LPC82X_JHI33_analog.kicad_pcb, LPC82X_JHI33_analog.sch]
2019-04-26 fixed uart output, some cleanup from playground
    [board.hpp, lpc824JHI33_protoboard.cpp]
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2019-05-14 fixed weird trace position
    [LPC82X_JHI33_testjig.kicad_pcb]
2019-05-15 fixed DRC error by updating footprint, rendered plots
    [LPC82X_JHI33.kicad_pcb, LPC82X_JHI33_analog.kicad_pcb]
2019-05-21 fixed problem with ADC offset
    [lpc824JHI33_protoboard.cpp]
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2019-06-19 fixed bug that you would never fail on maximum timeouts
    [gpio_tester.cpp]
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2019-07-10 needed relayout as moving stuff off sheet will reset it
    [LPC82X_JHI33.kicad_pcb]
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2019-07-19 fixed incorrect path for schematic library
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
